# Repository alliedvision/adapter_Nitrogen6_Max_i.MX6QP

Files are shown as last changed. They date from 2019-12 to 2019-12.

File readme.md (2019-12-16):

# Allied Vision Adapter Board CSI-2 for Nitrogen Max i.MX6

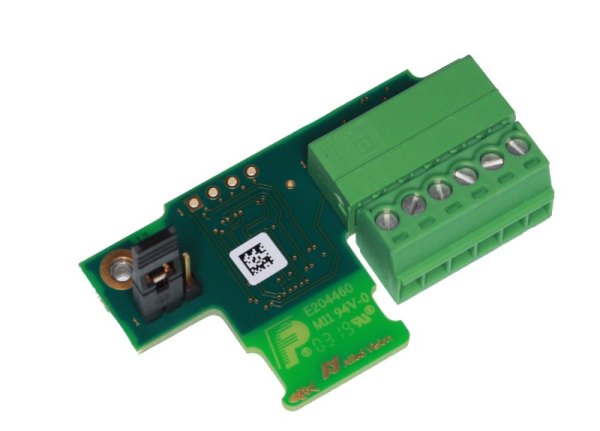
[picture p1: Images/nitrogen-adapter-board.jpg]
nitrogen-adapter-board


This repository contains open hardware design files for an adapter board supporting the Allied Vision Alvium CSI-2 camera pinout to Boundary Devices Nitrogen6_MAX, created by Allied Vision.
The board allows the user to interface with one Alvium MIPI CSI-2 compatible camera over a Flexible Flat Cable (FFC) connector.

This adapter can also be ordered at [Allied Vision](https://www.alliedvision.com/en/meta-header/contact-us/contact-sales.html) or a [qualified Allied Vision distributor](https://www.alliedvision.com/en/about-us/where-we-are.html) under order code **12314** - Adapter Board CSI-2 Nitrogen Max.

## Getting Started

These instructions will get you a copy of the design files to make your own adapter boards for development and testing purposes. 
The board can be produced and assembled using the provided design files. Please take a look at the mechanical layers for more information regarding the PCB stackup recommended for fabrication. 

See our [website](https://www.alliedvision.com/en/support/technical-documentation/alvium-csi-2-documentation.html) for further documentation and installation guides of the finished boards.

### Prerequisites

* A running installation of Altium.
* A PCB producer & PCBA manufacturer or some soldering skills.
* One supported embedded board Nitrogen i.MX6 series:
	* Nit6Q_MAX_QCA_BRD i.MX6 Quad
	* Nit6Q_MAX_QCA_BRD i.MX6 QuadPlus
* One supported MIPI CSI-2 FPC cable
	* Allied Vision part numbers #12316, 12317, 12318
* [One Allied Vision Alvium CSI-2 camera](https://www.alliedvision.com/en/products/embedded-vision-cameras.html)

### Installing

Open the *CSI2-NITROGEN_Rev01.PrjPcb* project file in your Altium environment.

## Built With

* [Altium Designer 19](https://www.altium.com/altium-designer/de)
 
## License

This project is licensed under the MIT License - see the [LICENSE](LICENSE) file for details

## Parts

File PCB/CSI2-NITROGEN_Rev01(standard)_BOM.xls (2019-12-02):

 | Bill of Materials | CSI2-NITROGEN_Rev01
 | Project : | CSI2-NITROGEN
 | PCBA : |  | Revision : | 01
 | PCB : |  | Revision : | 01
 | Variant : | standard
 | Schematic : | CSI2-NITROGEN_Rev01 | Schematic.pdf
 | Placement : | CSI2-NITROGEN_Rev01 | Overlay.pdf
 | Report Date : | 27.11.2019 | 15:36
 | Alternative Parts :
Quantity | Designator | Comment | Footprint | Description | Manufacturer | Manufacturer Part Number | KHK Part Number
1 | C1 | 100n | C-0603_1.0 | Capacitor Ceramic SMD/0603/50V/X7R/10% | several | several | K8340023
2 | C2, C3 | 10u | C-0603_1.0 | Capacitor Ceramic SMD/0603/10V/X7T/20%/125°C | several | several | 10509
1 | D1 | ESD9B5.0ST5G | D-SOD923 | DIODE TVS; 400W; 5.8-7.8V; BIDIRECT | ON Semiconductor | ESD9B5.0ST5G | 7250
1 | D2 | Green | D-0603-SLED | Side LED 0603 20mA green | several | several | 4248
1 | J1 | CON1x3 | CON 1x3 RM2.54 | Stiftleiste; 1x3; 2.54mm; gerade | fischer elektronik | SL 11 124 3 G | K7600610
1 | J2 | Jumper | J-JUMPER-2.54 | CON/JUMPER/STC02SYAN; 2-pin; 2.54mm; 3A; FEMALE; VERTICAL; BLACK | several | several | 13444
1 | J3 | NL | CON 1x4 RM2.54 | Stiftleiste; 1x4; 2.54mm; gerade | Harwin | M20-999 0445
1 | J4 | MC 1,5/6-G-3,5 | CON_MiniCon 6pol 3mm5 | Phoenix MC 1,5/6-G-3,5 MiniCon 6polig 3,5mm | Phoenix | MC 1,5/6-G-3,5 | K7600569
1 | J5 | CON FFC22_Inverted | J-FH55-22S-0.5SH - Inverted Pins | FFC Connector 0.5mm shielded | Hirose | FH55-22S-0.5SH | 10357
1 | J6 | 53748-0308 | J-MOLEX-53748-0308 | 30pin B2B plug 0.5 pitch 3mm Height | Molex | 53748-0308 | 10287
1 | J40 | MC 1,5/6-ST-3,5 |  | Phoenix MC 1,5/6-ST-3,5 MiniCon 6polig 3,5mm | Phoenix | MC 1,5/6-ST-3,5 | 1818
1 | LA1 | LABEL 7x7mm | PCB LABEL 7x7 | LABEL 7x7mm | several | several
4 | MRK1, MRK2, MRK3, MRK4 | Marker Single Layer | PCB_Marker_Pad_top | Position Marker for PCBs
1 | PCB1 | 11288-04 |  | PCB ML04 | several | 11288-04 | 11288-04
2 | R1, R2 | 11k | R-0603_0.6 | Standard Resistor SMD/0603/1%/100mW/TK100 | several | several | K8250147
1 | R3 | 1k0 | R-0603_0.6 | Standard Resistor SMD/0603/1%/100mW/TK100 | several | several | K8250040
3 | R4, R5, R8 | NL | R-0603_0.6 | Standard Resistor SMD/0603/1%/100mW/TK100
2 | R6, R7 | 0R0 | R-0603_0.6 | Standard Resistor SMD/0603/1%/100mW/TK100 | several | several | K8250041
1 | U1 | NCP380HMUAJAATBG | IC-DFN06_2.0x2.0x0.8 | IC/PWR/LOADSW;1V2-5V5;3A;0R03/WLCSP6/1x1.5x0.63mm | onsemi | NCP380HMUAJAATBG | 13676
1 | X1 | PCB Spacer M2x3 | X-HOLE-2.9-4.0-DK_AH_3.0 | Abstandsbuchse SMTSO-2,1-3 ET | KVT | SMTSO-2,1-3 ET | 3291

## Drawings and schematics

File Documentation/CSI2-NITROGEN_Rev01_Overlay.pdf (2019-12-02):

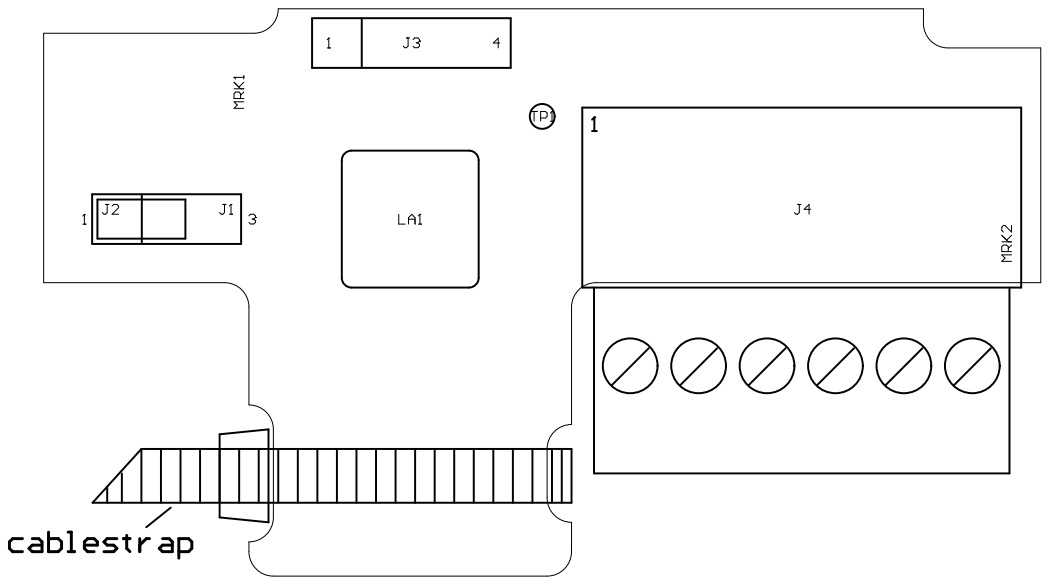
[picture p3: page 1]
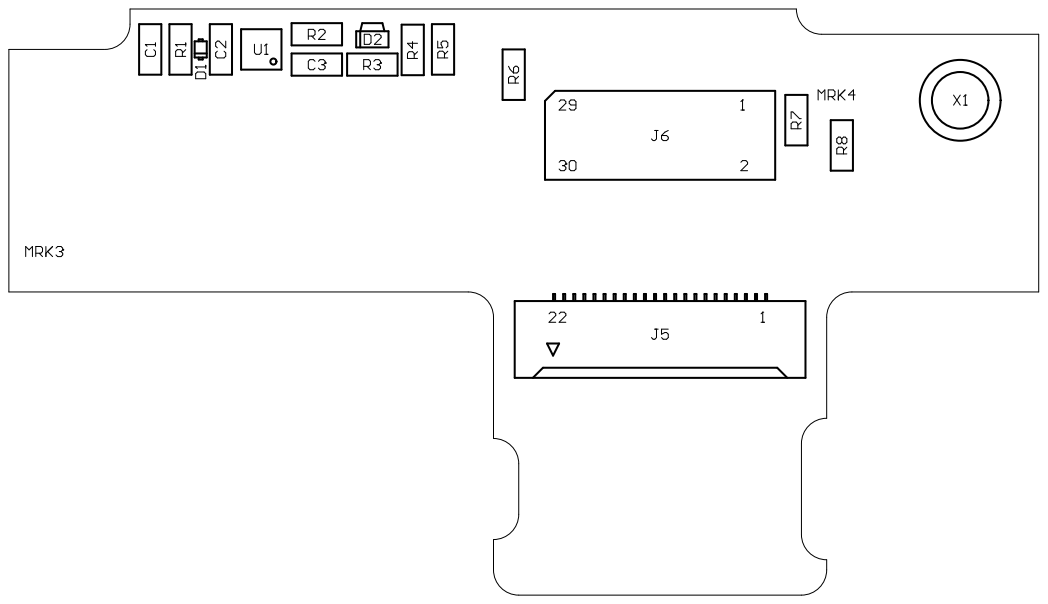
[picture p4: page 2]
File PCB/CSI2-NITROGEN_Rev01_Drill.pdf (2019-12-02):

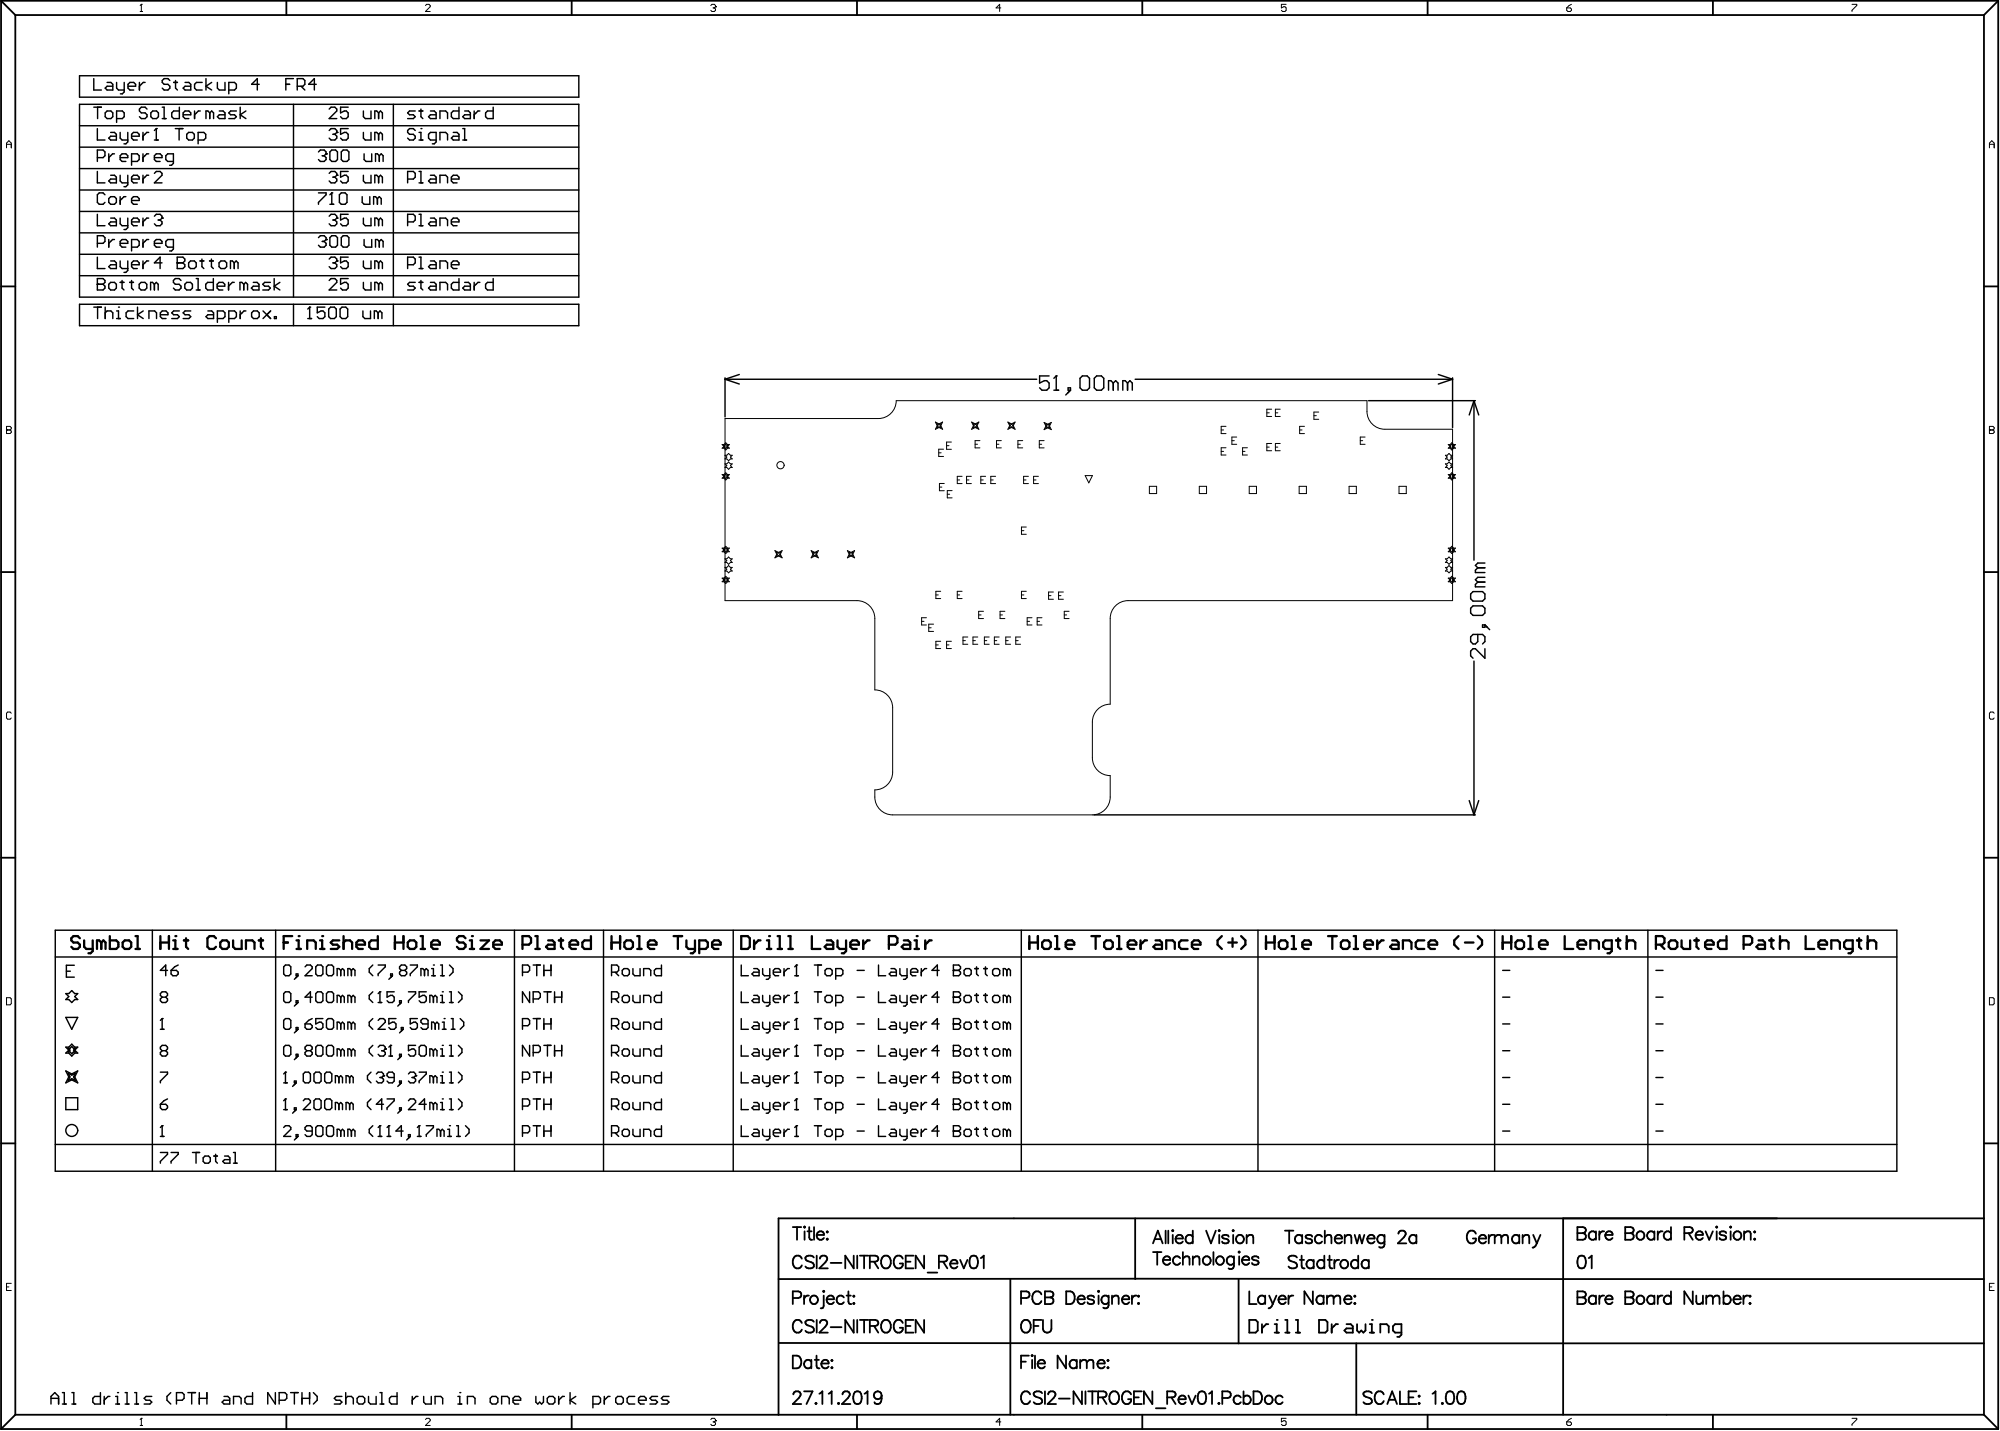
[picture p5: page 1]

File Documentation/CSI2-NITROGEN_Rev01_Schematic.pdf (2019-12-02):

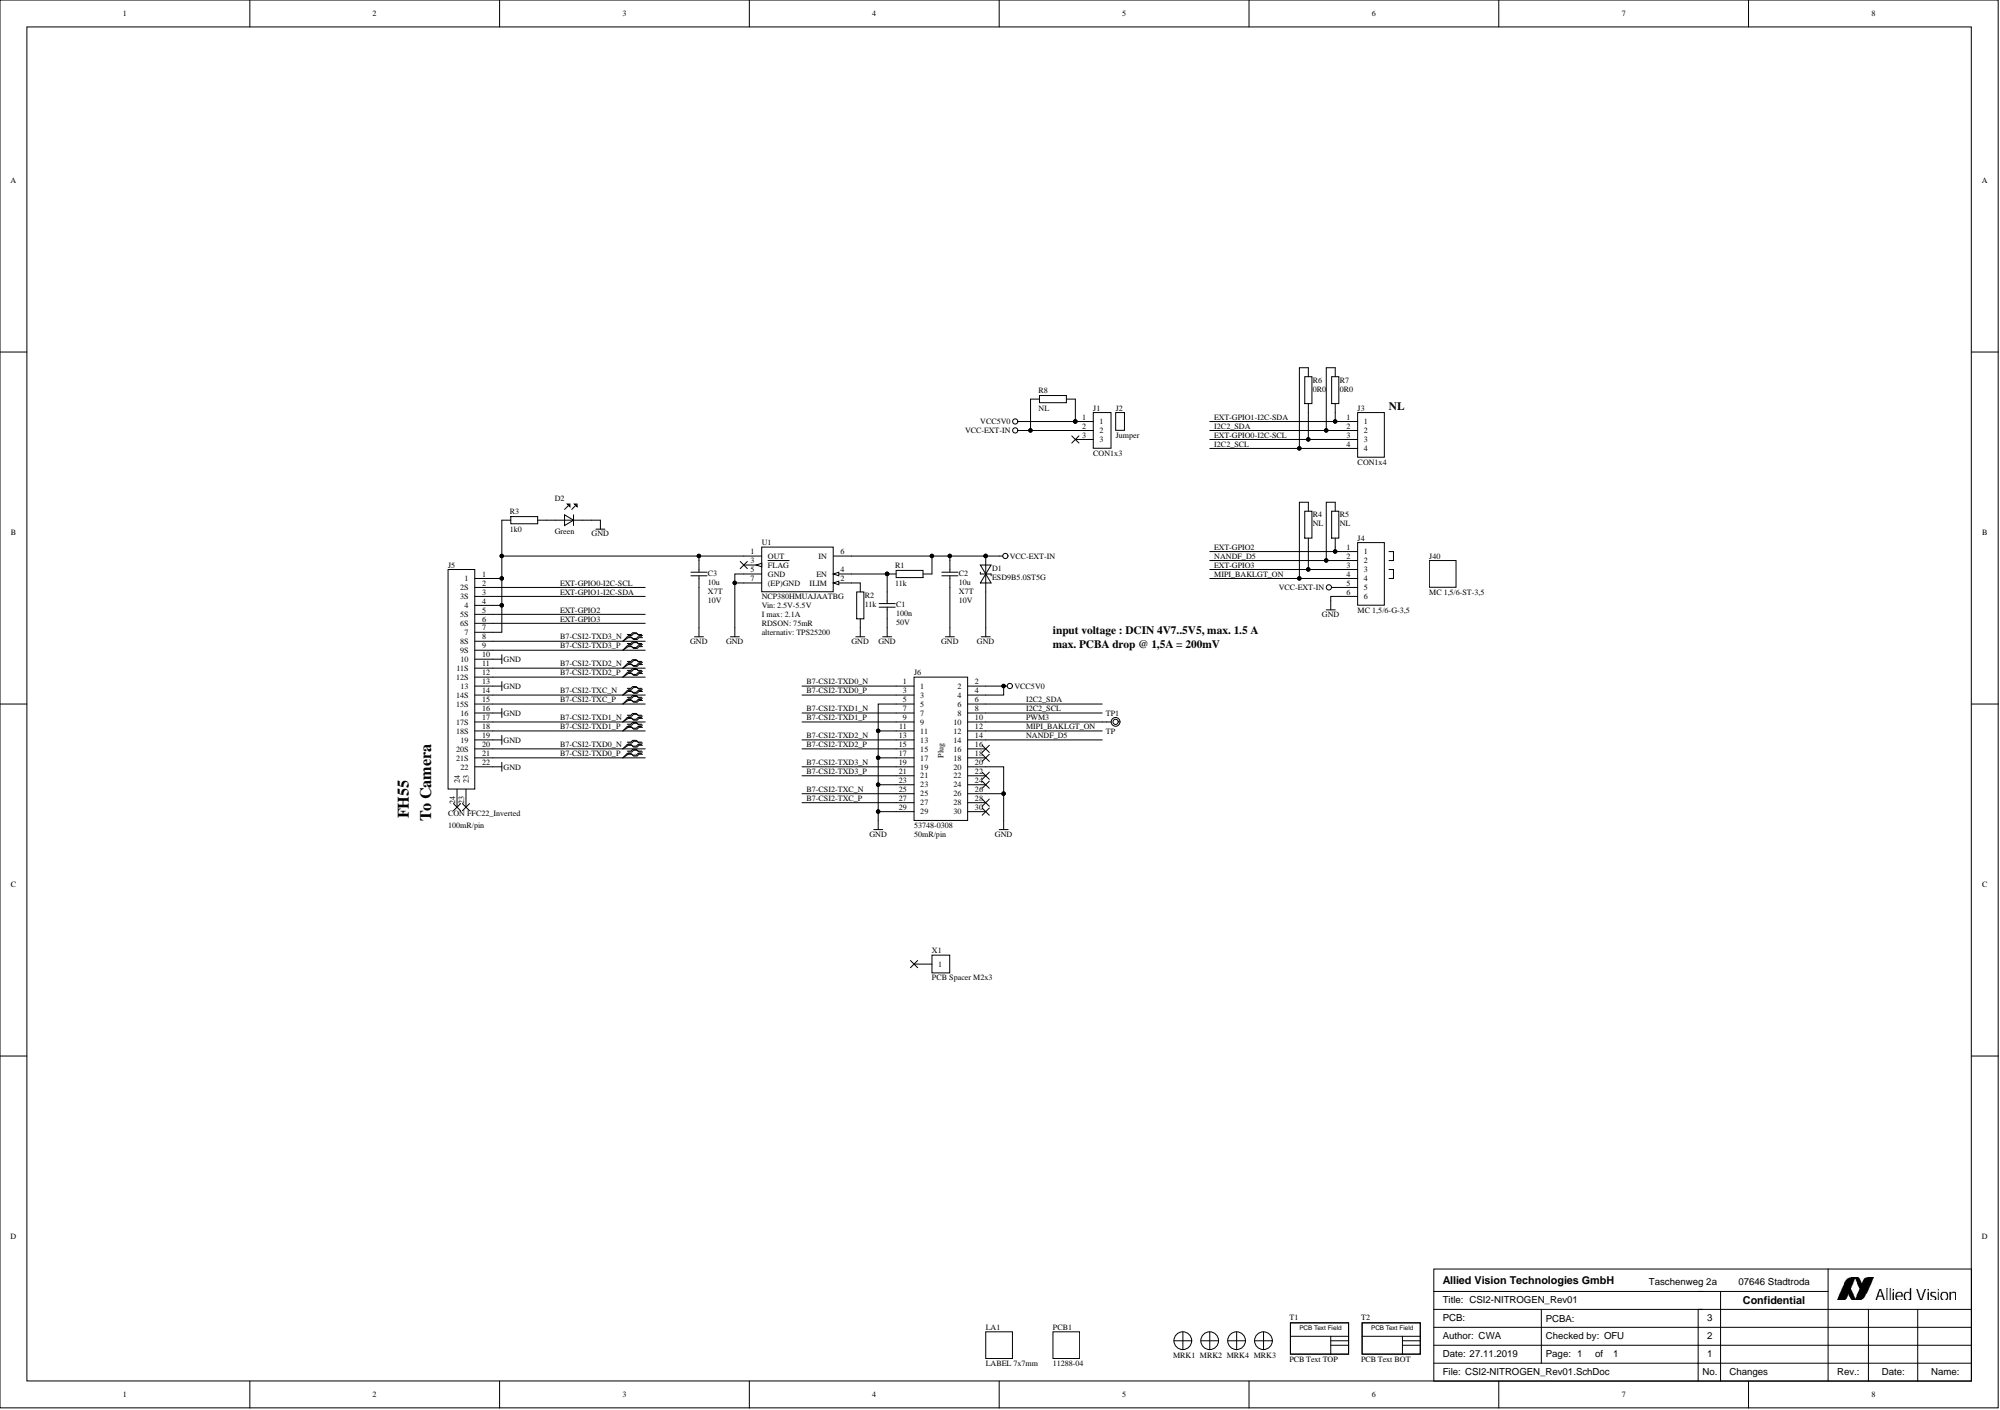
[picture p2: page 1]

FLAG 3 | R1

input voltage : DCIN 4V7..5V5, max. 1.5 A
max. PCBA drop @ 1,5A = 200mV

Allied Vision Technologies GmbH Taschenweg 2a 07646 Stadtroda

Title: CSI2-NITROGEN_Rev01 | Confidential

Author: CWA | Checked by: OFU | 2

Date: 27.11.2019 | | 1

File: CSI2-NITROGEN_Rev01.SchDoc | | No. | Changes | Rev.: | Date: | Name:
